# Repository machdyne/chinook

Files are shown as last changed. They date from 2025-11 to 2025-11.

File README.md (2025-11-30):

# Chinook Computer

Chinook is a metacomputer designed by Lone Dynamics Corporation.

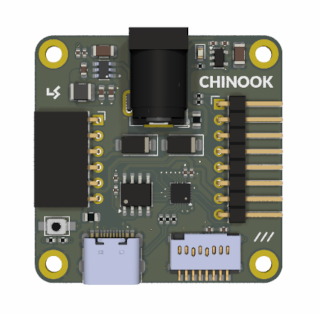
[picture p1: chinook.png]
Chinook


This repo will contain schematics, PCB layouts, pinouts, a 3D-printable case and documentation.

Find more information on the [Chinook product page](https://machdyne.com/product/chinook-computer/).

## Bootloader

Chinook uses the [rv003usb](https://github.com/cnlohr/rv003usb) bootloader to support firmware updates over the USB-C connector. If overwritten, it can be restored with the SWIO pin and an external programmer.

## Linux

Chinook uses a slightly modified [fork](https://github.com/machdyne/linux-ch32v003) of [linux-ch32v003](https://github.com/tvlad1234/linux-ch32v003).

Build with `make -f Makefile.chinook`.

## Power

Chinook can be powered through the barrel jack connector (or the PWRJACK pin) or the USB-C connector.

## Pinouts

### Left connector

This connector is compatible with HC-05/06 bluetooth modules, make sure the pins match the pinout below when plugging the module in (it may need to be upside down).

| Pin | Signal | Description |
| --- | --- | --- |
| 1 | NC | not connected |
| 2 | TX | MCU UART transmit / bluetooth RX |
| 3 | RX | MCU UART receive / bluetooth TX |
| 4 | GND | Ground |
| 5 | PWR5V0 | 5V output |
| 6 | HCEN | High = HC-05/06 UART mode, Low = AT comamnd mode |

### Right connector

This connector is for general purpose I/O and optional power input/output.

| Pin | Signal | Description |
| --- | --- | --- |
| 1 | GPIOA | GPIO / I2C SCL |
| 2 | GPIOB | GPIO / I2C SDA |
| 3 | GPIOC | GPIO / ADC1 |
| 4 | GPIOD | GPIO / ADC0 |
| 5 | SWIO | MCU programming pin |
| 6 | GND | Ground |
| 7 | PWR3V3 | 3.3V output |
| 8 | PWRJACK | Power input (9-15V) connected to barrel jack |

## License

The contents of this repo are released under the [Lone Dynamics Open License](LICENSE.md).

Note: You can use these designs for commercial purposes but we ask that instead of producing exact clones, that you either replace our trademarks and logos with your own or add your own next to ours.

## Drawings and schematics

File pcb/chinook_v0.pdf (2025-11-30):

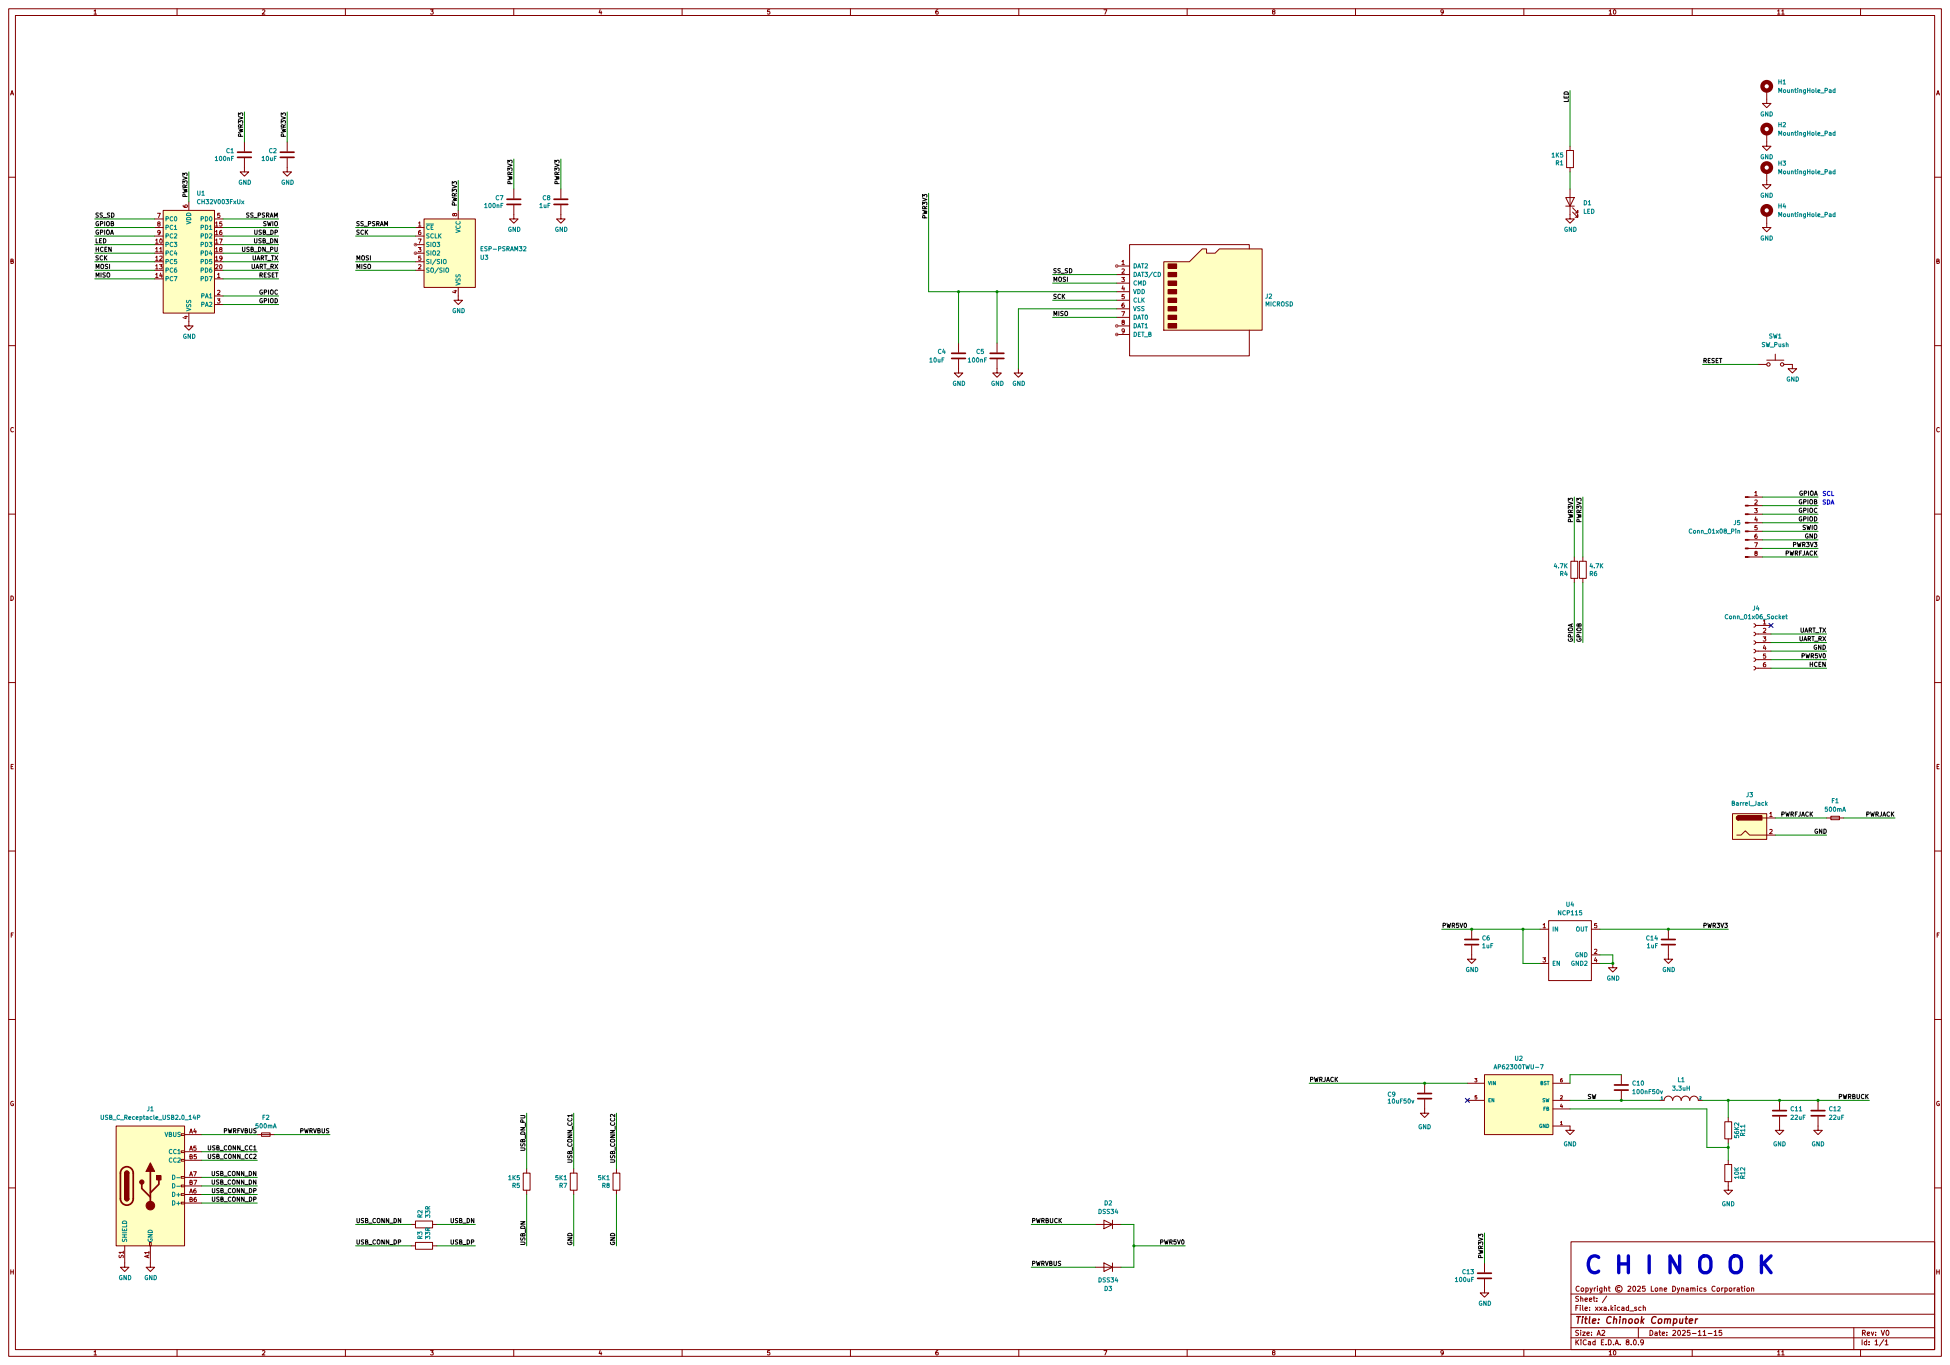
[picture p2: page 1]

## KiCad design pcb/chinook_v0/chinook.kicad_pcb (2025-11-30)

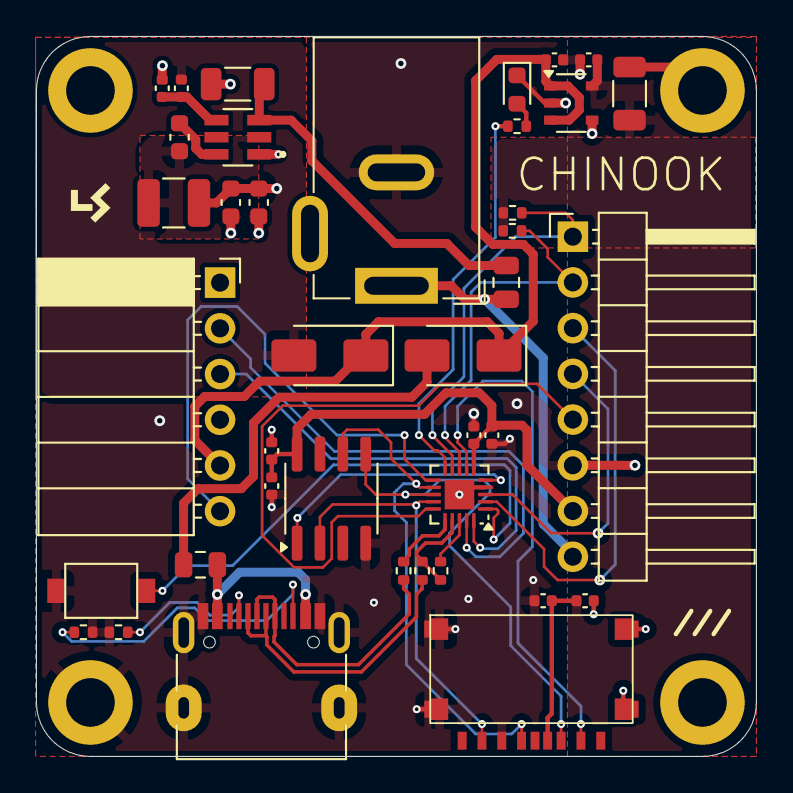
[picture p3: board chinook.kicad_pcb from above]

Board: 2 copper layers, 40.0 x 40.0 mm, 43 parts (0 on the bottom side), 34 nets.

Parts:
C1, C5, C7: 100nF; C_0402_1005Metric
C2, C4: 10uF; C_0402_1005Metric
C6, C8, C14: 1uF; C_0402_1005Metric
C9: 10uF50v; C_1206_3216Metric
C10: 100nF50v; C_0603_1608Metric
C11, C12: 22uF; C_0603_1608Metric
C13: 100uF; C_1206_3216Metric
D1: LED; LED_0603_1608Metric
D2, D3: DSS34; D_SMA
F1, F2: 500mA; Fuse_0805_2012Metric
H1, H2, H3, H4: MountingHole_Pad; MountingHole_2.7mm_M2.5_DIN965_Pad
J1: USB_C_Receptacle_USB2.0_14P; USB_C_Receptacle_HRO_TYPE-C-31-M-12-BIG-PADS-PASTE
J2: MICROSD; TF-018B-H15-HAND-SOLDER
J3: Barrel_Jack; BarrelJack_GCT_DCJ200-10-A_Horizontal
J4: Conn_01x06_Socket; PinSocket_1x06_P2.54mm_Horizontal
J5: Conn_01x08_Pin; PinHeader_1x08_P2.54mm_Horizontal
L1: 3.3uH; L_1210_3225Metric
R1, R5: 1K5; R_0402_1005Metric
R2, R3: 33R; R_0402_1005Metric
R4, R6: 4.7K; R_0402_1005Metric
R7, R8: 5K1; R_0402_1005Metric
R11: 56K2; C_0402_1005Metric
R12: 10K; C_0402_1005Metric
SW1: SW_Push; Button_2P_3x4mm
U1: CH32V003FxUx; QFN-20-1EP_3x3mm_P0.4mm_EP1.65x1.65mm
U2: AP62300TWU-7; SOT95P280X100-6N
U3: ESP-PSRAM32; SOIC-8_3.9x4.9mm_P1.27mm
U4: NCP115; TSOP-5_1.65x3.05mm_P0.95mm

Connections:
/GPIOA: J5.1, R4.1, U1.9 (PC2)
/GPIOB: J5.2, R6.1, U1.8 (PC1)
/GPIOC: J5.3, U1.2 (PA1)
/GPIOD: J5.4, U1.3 (PA2)
/HCEN: J4.6, U1.11 (PC4)
/LED: R1.2, U1.10 (PC3)
/MISO: J2.7 (DAT0), U1.14 (PC7), U3.2 (SO/SIO)
/MOSI: J2.3 (CMD), U1.13 (PC6), U3.5 (SI/SIO)
/PWR3V3: C1.1, C2.1, C4.1, C5.1, C7.1, C8.1, C13.1, C14.1, J2.4 (VDD), J5.7, R4.2, R6.2, U1.6 (VDD), U3.8 (VCC), U4.5 (OUT)
/PWR5V0: C6.1, D2.1 (K), D3.1 (K), J4.5, U4.1 (IN), U4.3 (EN)
/PWRBUCK: C11.1, C12.1, D2.2 (A), L1.2, R11.2
/PWRFJACK: F1.1, J3.1, J5.8
/PWRFVBUS: F2.1, J1.A4 (VBUS), J1.A9 (VBUS), J1.B4 (VBUS), J1.B9 (VBUS)
/PWRJACK: C9.1, F1.2, U2.3 (VIN)
/PWRVBUS: D3.2 (A), F2.2
/RESET: SW1.1, U1.1 (PD7)
/SCK: J2.5 (CLK), U1.12 (PC5), U3.6 (SCLK)
/SS_PSRAM: U1.5 (PD0), U3.1 (~CE)
/SS_SD: J2.2 (DAT3/CD), U1.7 (PC0)
/SW: C10.2, L1.1, U2.2 (SW)
/SWIO: J5.5, U1.15 (PD1)
/UART_RX: J4.3, U1.20 (PD6)
/UART_TX: J4.2, U1.19 (PD5)
/USB_CONN_CC1: J1.A5 (CC1), R7.2
/USB_CONN_CC2: J1.B5 (CC2), R8.2
/USB_CONN_DN: J1.A7 (D-), J1.B7 (D-), R2.1
/USB_CONN_DP: J1.A6 (D+), J1.B6 (D+), R3.1
/USB_DN: R2.2, R5.1, U1.17 (PD3)
/USB_DN_PU: R5.2, U1.18 (PD4)
/USB_DP: R3.2, U1.16 (PD2)
GND: C1.2, C2.2, C4.2, C5.2, C6.2, C7.2, C8.2, C9.2, C11.2, C12.2, C13.2, C14.2, D1.1 (K), H1.1, H2.1, H3.1, H4.1, J1.A1 (GND), J1.A12 (GND), J1.B1 (GND), J1.B12 (GND), J1.S1 (SHIELD), J2.6 (VSS), J3.2, J4.4, J5.6, R7.1, R8.1, R12.1, SW1.2, U1.4 (VSS), U1.21 (VSS), U2.1 (GND), U3.4 (VSS), U4.2 (GND), U4.4 (GND2)
unnamed: D1.2 (A), R1.1
unnamed: C10.1, U2.6 (BST)
unnamed: R11.1, R12.2, U2.4 (FB)

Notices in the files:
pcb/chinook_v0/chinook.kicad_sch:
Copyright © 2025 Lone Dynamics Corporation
